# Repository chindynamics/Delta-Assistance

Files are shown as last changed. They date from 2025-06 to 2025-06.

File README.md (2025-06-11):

# Delta Assistance

**Delta Assistance** is an assisted mobility system designed for individuals with paralysis or reduced mobility, controlled through eye-tracking. The project combines computer vision, hardware control, and accessible design to offer a functional, low-cost, and adaptable solution. This repository contains all the code, technical documentation, and resources necessary to replicate or understand the development of the project.

## CONTENT

Below are the sections available to explore the project in more detail:  
- [Introduction](https://github.com/chindynamics/Delta-Assistance/blob/main/docs/en/1.-%20introduction.md): context, motivation, and project objectives.  
- [Installation](https://github.com/chindynamics/Delta-Assistance/blob/main/docs/en/2.-%20installation.md): step-by-step guide to clone the repository, install dependencies, and run the system.  
- [Documentation](https://github.com/chindynamics/Delta-Assistance/blob/main/docs/en/3.-%20documentation.md): full technical explanation of the design, integration, and validation process.

## FEATURES

The Delta Assistance system is designed to be accessible, modular, and adaptable. Its main innovation lies in the use of computer vision to interpret the user's gaze direction and convert it into commands to move a powered wheelchair. The eye-tracking interface was developed in Python based on Jason Orlosky's open-source code, while motion control was implemented on an Arduino Mega microcontroller using C++. This combination enables efficient communication between the user and the machine, even without physical contact.

In addition to the eye-tracking interface, a custom circuit board was designed to control the wheelchair motors, and a physical structure was adapted to integrate with a conventional wheelchair. The system is capable of recognizing five commands: move forward, move backward, turn left, turn right, and stop. Its design takes into account real-world environments, including varying lighting conditions and physical interference.

## COLLABORATION

This project was developed by the Delta Assistance team:

- [@chindynamics](https://github.com/chindynamics) – Lead on computer vision pipeline and human–computer interaction design.
- [@Sarao2341](https://github.com/Sarao2341) – Responsible for 3D modeling and mechanical integration.
- [@reginaruizz](https://github.com/reginaruizz) – PCB schematic and layout. Selected components for the power regulation stages.
- [@Ulin78](https://github.com/Ulin78) – Electronics integration and firmware support. Assisted with PCB bring-up.
- [@haydeevazquez](https://github.com/haydeevazquez) – Sound processing and obstacle detection.
- [@mirelyyc](https://github.com/mirelyyc) – UI and iconography designer. Created the visual assets for the desktop interface.

If you're interested in improving this system, adapting it to new needs, or contributing your expertise in software, hardware, or accessible design, you're welcome to collaborate. You can do so by opening an issue to report problems or suggestions, or by submitting a pull request with specific improvements. This project may also serve as an educational or research base for further developments in biomedical engineering and assistive technologies.

## LICENSE

This project is distributed under the [MIT License](https://github.com/chindynamics/Delta-Assistance/blob/main/LICENSE), meaning you are free to use, modify, and redistribute the code and resources shared here, as long as proper credit is given to the original authors.

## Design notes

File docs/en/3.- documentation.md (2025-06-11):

# DEVELOPMENT DOCUMENTATION

This section outlines step-by-step how the Delta Assistance project was developed—an electric wheelchair controlled by eye-tracking, aimed at improving mobility for individuals with paralysis or severe motor disabilities. Below are the detailed phases of the process, from initial concept to final system integration.

## SYSTEM DESIGN

The architecture was based on three main components:
- An eye-tracking interface that captures the user's gaze position to interpret movement commands within a digital interface designed using Qt Designer.
- An Arduino Mega microcontroller to interpret the signals sent from the Raspberry Pi and transmit commands to the wheelchair motors.
- A motor control system that moves the wheelchair in the desired direction safely.

## SOFTWARE DEVELOPMENT

The software was divided into two layers. The first is a visual interface developed in Python, which uses computer vision to analyze eye position and determine whether the user wants to move forward, backward, left, right, or stop. This interface translates the gaze direction into signals sent to the second layer: the microcontroller.  
The Arduino Mega was programmed in C++ using the Arduino environment. Its function is to receive commands, generate the appropriate motor control signals (using PWM), and ensure precise and safe control. Debugging messages were also included to facilitate testing.

## HARDWARE DEVELOPMENT

On the physical side, a standard wheelchair was modified by adding electronically controllable motors. A custom PCB was designed to mount the Arduino Mega and other components, such as voltage regulators and connection ports.  
An autonomous power system with rechargeable batteries was integrated, along with a fixed mount for the eye-tracking camera, positioned in front of the user's face. The entire system was built with a focus on ease of maintenance and durability for continuous use.

## INTEGRATION AND CALIBRATION

Once both the software and hardware stages were completed, all modules were integrated. An initial calibration process was designed for each user, allowing adjustment of eye sensitivity values.  
Various lighting conditions and distances were tested to ensure the system functions reliably under real-world scenarios.

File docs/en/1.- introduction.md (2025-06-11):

# INTRODUCTION

Neuromuscular conditions such as amyotrophic lateral sclerosis (ALS) or spinal cord injuries lead to progressive mobility loss, forcing patients into critical dependency for daily activities. In response to this challenge, our project presents an electric wheelchair controlled by eye tracking, a solution that empowers users to regain autonomy through technology. Unlike commercial systems that require physical components (such as joysticks or switches), our prototype interprets the user's intention to move directly from their gaze, removing barriers for those who have lost muscular control.

The system combines computer vision algorithms for iris tracking with a semi-autonomous navigation module. Using a low-cost camera and real-time image processing techniques, the software translates eye coordinates into directional commands (forward, backward, turns) that are sent to an Arduino Mega controller. At the same time, ultrasonic sensors and an integrated accelerometer detect obstacles within a 1.5-meter radius, activating automatic brakes when collision risk exceeds predefined thresholds. This safety layer is essential for indoor environments with limited space.

Statistics emphasize the urgency of such solutions, ALS has a global incidence of 1.9 cases per 100,000 people, with a projected 69% increase by 2040 due to population aging. Yet, access to assistive technologies remains limited.

This project not only demonstrates the technical feasibility of accessible systems, but also opens the door to future improvements.

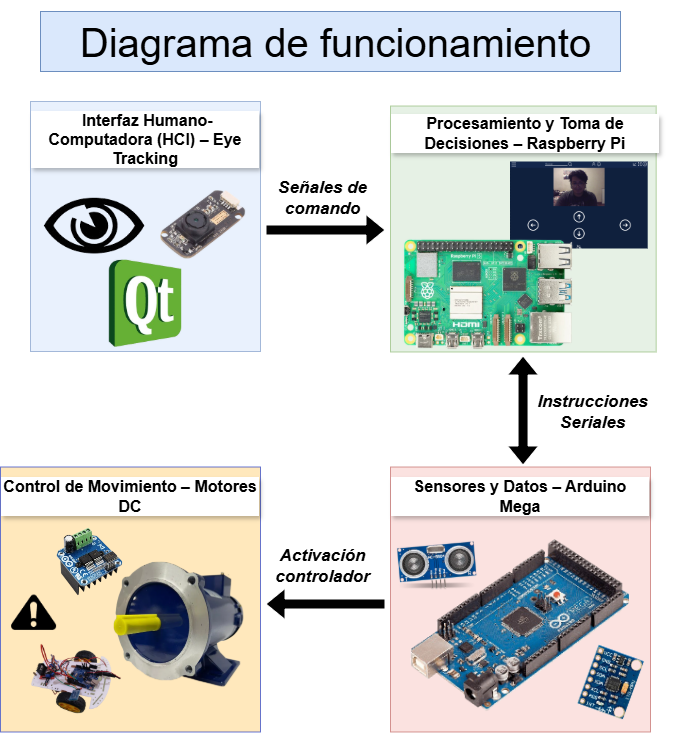
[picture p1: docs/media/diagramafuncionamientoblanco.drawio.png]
System Architecture


*Figure 1: System data flow. The camera captures eye movement, the algorithm translates it into coordinates, and Arduino sends signals to the motors, while ultrasonic sensors monitor the surroundings.*

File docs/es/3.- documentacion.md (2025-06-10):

# DOCUMENTACIÓN DE DESARROLLO

Este apartado describe paso a paso cómo se llevó a cabo el desarrollo del proyecto Delta Assistance, una silla de ruedas eléctrica controlada mediante seguimiento ocular, orientada a mejorar la movilidad de personas con parálisis o discapacidades motoras severas. A continuación se detallan las fases del proceso, desde la concepción inicial hasta la integración final de los sistemas.

## DISEÑO DEL SISTEMA

Se planteó una arquitectura basada en tres elementos principales:
- Una interfaz de seguimiento ocular. Captura la posición de la mirada del usuario para interpretar comandos de movimiento en una interfaz digital diseñada en Qt Designer.
- Un microcontrolador Arduino Mega para interpretar las señales mandadas desde el Raspberry Pi y enviar comandos a los motores de la silla.
- Un sistema de control de motores que mueve la silla de ruedas en la dirección deseada de forma segura.

## DESARROLLO DE SOFTWARE

El sistema de software se dividió en dos niveles. El primero es una interfaz visual desarrollada en Python, utilizando visión por computadora para analizar la posición de los ojos y determinar si el usuario desea moverse hacia adelante, atrás, a la izquierda, a la derecha o detenerse. Esta interfaz traduce la dirección de la mirada en señales que son enviadas al segundo nivel: el microcontrolador. El Arduino Mega fue programado en C++ mediante el entorno de Arduino, y su función es recibir los comandos, generar las señales adecuadas para los motores (usando PWM) y garantizar un control preciso y seguro. También se incluyeron mensajes de depuración para facilitar las pruebas.

## DESARROLLO DE HARDWARE

En el aspecto físico, se adaptó una silla de ruedas convencional agregando motores controlables electrónicamente. Se diseñó una PCB personalizada para montar el Arduino Mega y otros componentes como reguladores de voltaje y puertos de conexión. Además, se integró un sistema de energía autónoma con baterías recargables, y un soporte fijo para la cámara encargada del seguimiento ocular, ubicada frente al rostro del usuario. Todo el sistema fue construido considerando la facilidad de mantenimiento y la robustez frente al uso continuo.

## INTEGRACIÓN Y CALIBRACIÓN

Una vez finalizadas las etapas de software y hardware, se llevó a cabo la integración de todos los módulos. Se diseñó un proceso de calibración inicial para cada usuario, donde se ajustan los valores de sensibilidad ocular. También se probaron diferentes condiciones de iluminación y distancias para asegurar que el sistema funcionara correctamente en situaciones reales.

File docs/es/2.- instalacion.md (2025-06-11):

# INSTALACIÓN

Este apartado proporciona una guía paso a paso para instalar y configurar correctamente el sistema de control de la silla de ruedas eléctrica con seguimiento ocular. El objetivo es asegurar que cualquier usuario o desarrollador pueda poner en marcha el entorno de software y hardware sin complicaciones.

## REQUISITOS PREVIOS

Antes de comenzar con la instalación, asegurate de tener lo siguiente instalado:
- Una computadora con un sistema operativo Linux o Windos (no probado en macOS) o un Raspberry Pi.
- Un microcontrolador Arduino Mega, correctamente flasheado con el código proporcionado para Arduino.
- Una cámara infrarroja, para este proyecto se usó una cámara GC0308.
- Librerías de Python requeridas para el procesamiento de imágenes.

## CLONA EL REPOSITORIO

Clona este repositorio en tu máquina local usando el comando:

```bash
git clone https://github.com/chindynamics/Delta-Assistance.git
cd Delta-Assistance
```

## INSTALA LAS DEPENDENCIAS

Una vez clonado el repositorio, instala las dependencias necesarias. Se recomienda crear un entorno virtual de Python 3.11:

```bash
python -m venv venv
source venv/bin/activate
pip install -r requirements.txt
```

## PRIMER INICIO

Ejecuta el script principal **HCI.py** del sistema de seguimiento ocular para verificar la calibración y comunicación con el microcontrolador.

Al ejecutar este código, el sistema calibrará el seguimiento ocular. Observe los puntos en pantalla y presione la barra espaciadora para capturar los puntos de calibración, repita este proceso para cada punto para completar el proceso. Una vez calibrado, puede activar el control de movimiento desde la interfaz proporcionada usando el seguimiento ocular.

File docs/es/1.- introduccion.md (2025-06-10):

# INTRODUCCIÓN

Los padecimientos neuromusculares como la esclerosis lateral amiotrófica (ELA) o las lesiones medulares generan una pérdida progresiva de la movilidad, relegando a los pacientes a una dependencia crítica de terceros para actividades cotidianas. Frente a este desafío, nuestro proyecto desarrolla una silla de ruedas eléctrica controlada mediante seguimiento ocular, una solución que empodera a los usuarios reconquistando su autonomía a través de la tecnología. A diferencia de sistemas comerciales que requieren componentes físicos (como joysticks o pulsadores), nuestro prototipo interpreta la intención de movimiento directamente desde la mirada, eliminando barreras para quienes han perdido el control muscular.

El sistema combina algoritmos de visión por computadora para el rastreo del iris con un módulo de navegación autónoma. Utilizando una cámara de bajo costo y técnicas de procesamiento de imágenes en tiempo real, el software traduce coordenadas oculares en comandos direccionales (avance, retroceso, giros) que son enviados a un controlador Arduino Mega. Paralelamente, sensores ultrasónicos y un acelerómetro integrado detectan obstáculos en un radio de 1.5 metros, activando frenos automáticos cuando el riesgo de colisión supera umbrales predefinidos. Esta capa de seguridad es clave para entornos domésticos con espacios reducidos.

Las estadísticas subrayan la urgencia de estas soluciones, la incidencia global de ELA alcanza 1.9 casos por cada 100,000 personas, con un crecimiento proyectado del 69% para 2040 debido al envejecimiento poblacional. Sin embargo, el acceso a tecnologías asistivas sigue siendo limitado. 

Este proyecto no solo demuestra la viabilidad técnica de sistemas accesibles, sino que también abre puertas a futuras mejoras.

Arquitectura de Sistema

*Figura 1: Flujo de datos del sistema. La cámara captura el movimiento ocular, el algoritmo lo traduce en coordenadas, y Arduino envía señales a los motores, mientras los sensores ultrasónicos monitorizan el entorno.*

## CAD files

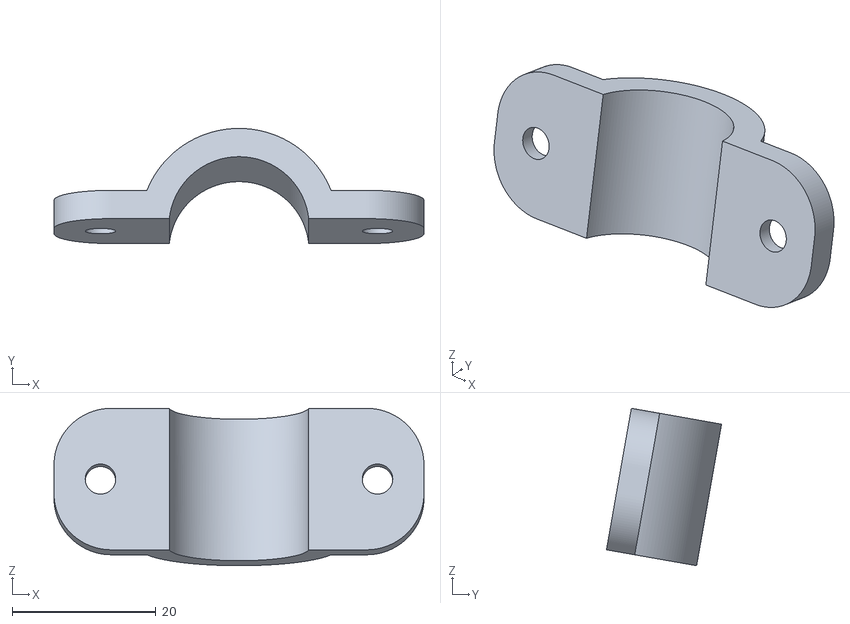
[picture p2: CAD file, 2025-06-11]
src/3D-modeling/CLAMP_ULTRASONICO.stl
51.5 x 16.0 x 21.9

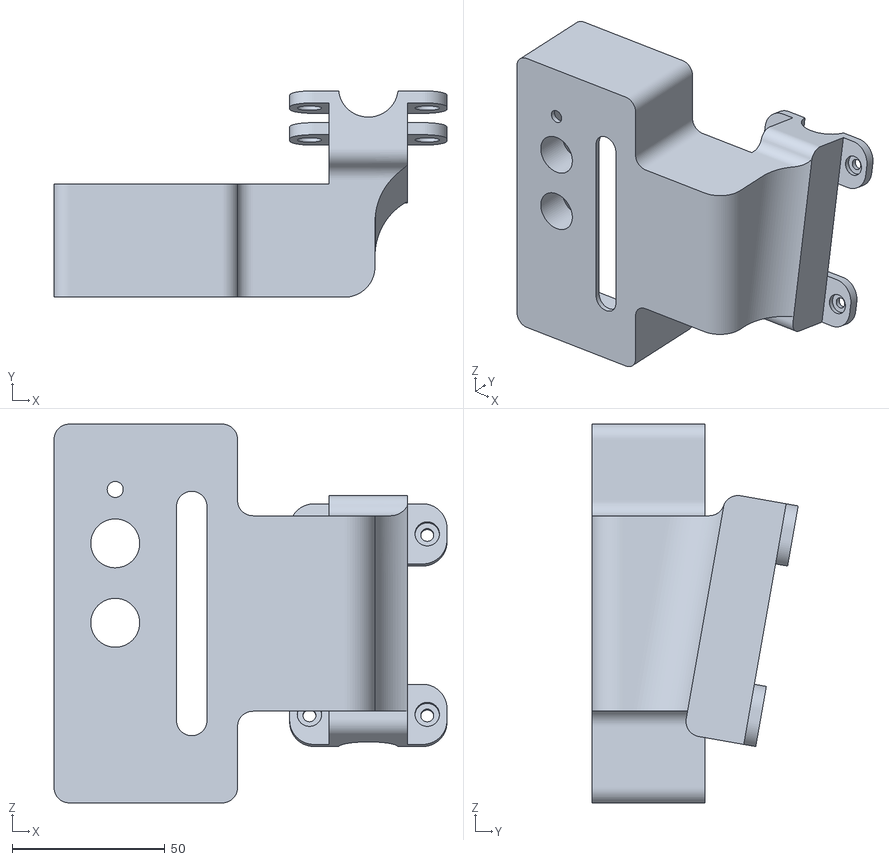
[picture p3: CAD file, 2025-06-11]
src/3D-modeling/DERECHACASE.stl
128.7 x 67.6 x 124.0

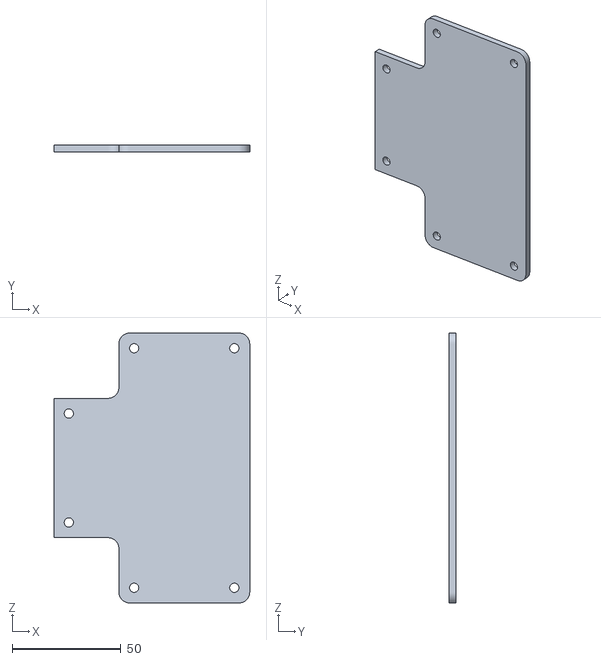
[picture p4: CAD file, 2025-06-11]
src/3D-modeling/IZQUIERDATAPA.stl
89.8 x 3.00 x 124.0

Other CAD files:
src/3D-modeling/IZQUIERDACASE.stl
src/3D-modeling/DERECHATAPA.stl
src/3D-modeling/EJE_MOTOR_REV2 v2.f3d
src/3D-modeling/ENSAMBLE_MONITOR v5.f3d
src/3D-modeling/EYETRACKER_SUPPORT v5.f3d
src/3D-modeling/MecanismoFreno v8 v2.f3d
src/3D-modeling/SENSOR TRASERO_DELTA_ULTRASÓNICO v5.f3z
src/3D-modeling/SOPORTE BOCINAS_DELTA v2.f3d
src/3D-modeling/sensores delantero v4.f3z

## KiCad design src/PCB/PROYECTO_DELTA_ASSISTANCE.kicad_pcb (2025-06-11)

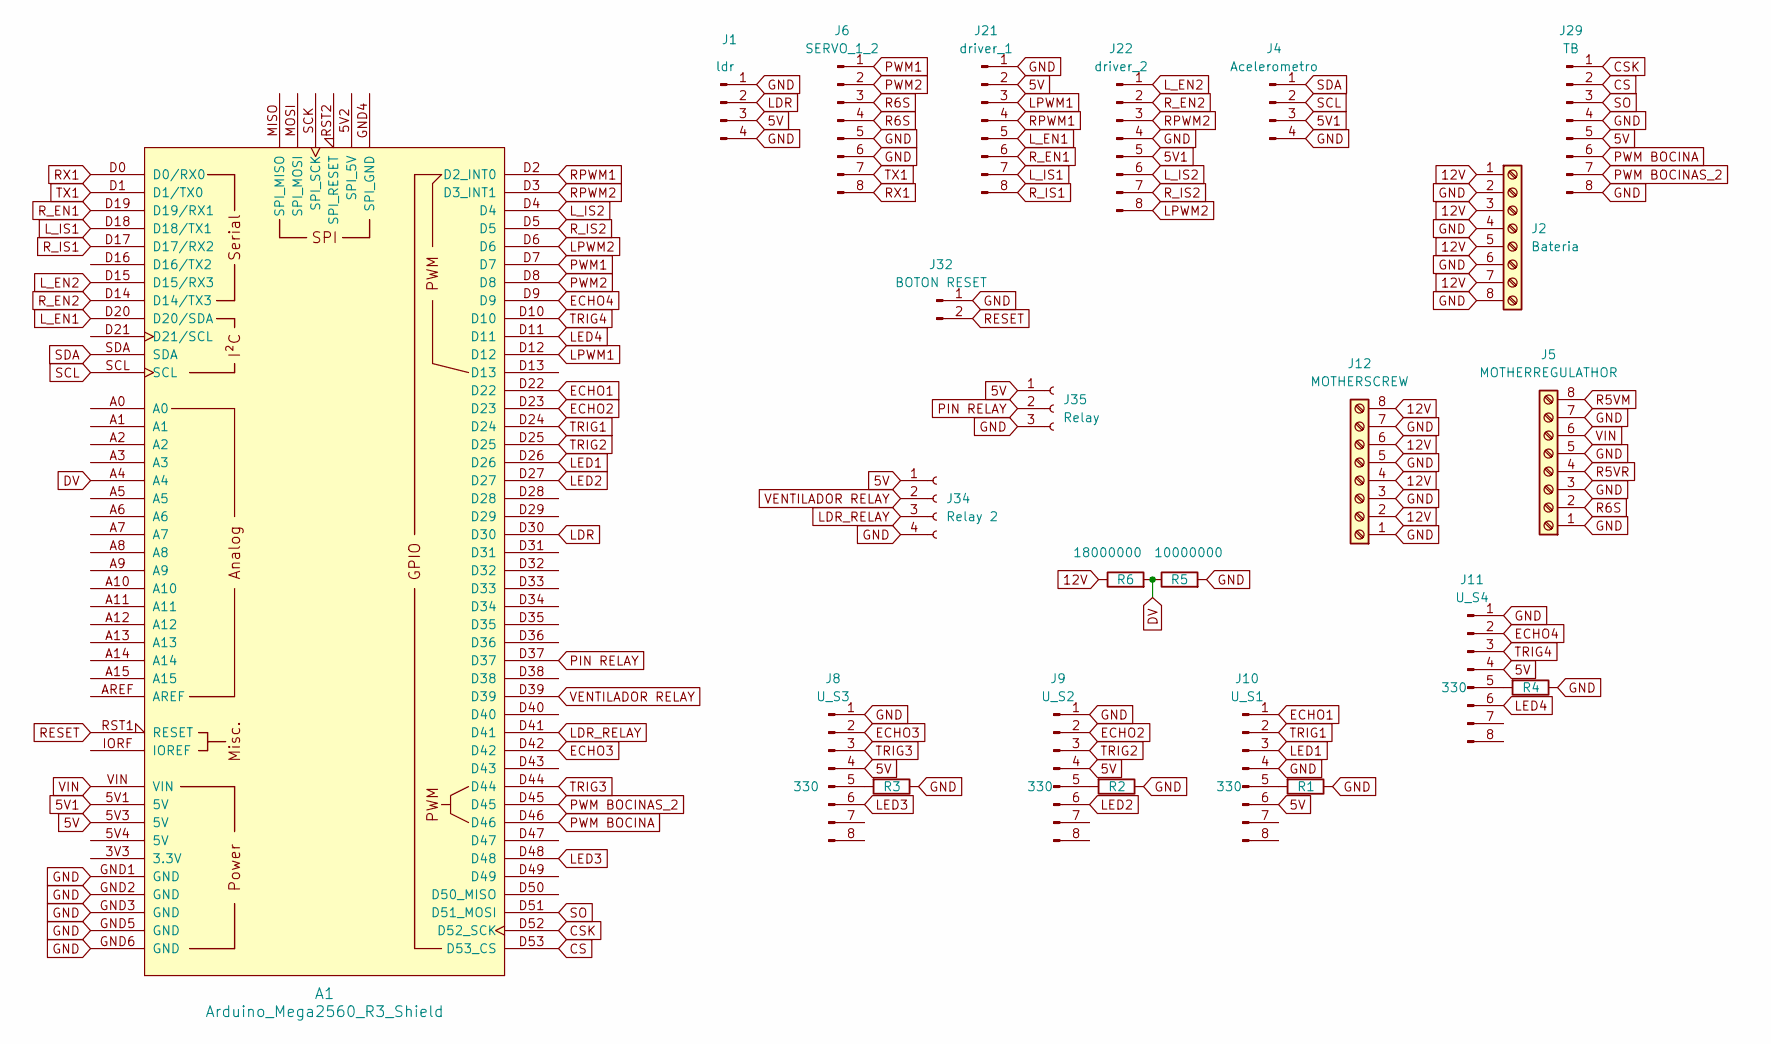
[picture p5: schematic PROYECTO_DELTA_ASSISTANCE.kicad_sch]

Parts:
A1: Arduino_Mega2560_R3_Shield
J1: ldr; JST_XH_B4B-XH-A_1x04_P2.50mm_Vertical
J2: Bateria; TerminalBlock_Phoenix_MKDS-1,5-8-5.08_1x08_P5.08mm_Horizont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
J4: Acelerometro; JST_XH_B4B-XH-A_1x04_P2.50mm_Vertical
J5: MOTHERREGULATHOR; TerminalBlock_Phoenix_MKDS-1,5-8-5.08_1x08_P5.08mm_Horizont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
J6: SERVO_1_2; JST_XH_B8B-XH-A_1x08_P2.50mm_Vertical
J8: U_S3; JST_XH_B8B-XH-A_1x08_P2.50mm_Vertical
J9: U_S2; JST_XH_B8B-XH-A_1x08_P2.50mm_Vertical
J10: U_S1; JST_XH_B8B-XH-A_1x08_P2.50mm_Vertical
J11: U_S4; JST_XH_B8B-XH-A_1x08_P2.50mm_Vertical
J12: MOTHERSCREW; TerminalBlock_Phoenix_MKDS-1,5-8-5.08_1x08_P5.08mm_Horizont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
J21: driver_1; JST_XH_B8B-XH-A_1x08_P2.50mm_Vertical
J22: driver_2; JST_XH_B8B-XH-A_1x08_P2.50mm_Vertical
J29: TB; JST_XH_B8B-XH-A_1x08_P2.50mm_Vertical
J32: BOTON RESET; JST_XH_B2B-XH-A_1x02_P2.50mm_Vertical
J34: Relay 2; PinHeader_1x04_P2.54mm_Vertical
J35: Relay; PinHeader_1x03_P2.54mm_Vertical
R1, R2, R3, R4: 330; R_Axial_DIN0207_L6.3mm_D2.5mm_P10.16mm_Horizontal
R5: 10000000; R_Axial_DIN0207_L6.3mm_D2.5mm_P10.16mm_Horizontal
R6: 18000000; R_Axial_DIN0207_L6.3mm_D2.5mm_P10.16mm_Horizontal

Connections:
5V: A1.5V3 (5V), J1.3, J8.4, J9.4, J10.6, J11.4, J21.2, J29.5, J34.1, J35.1
5V1: A1.5V1 (5V), J4.3, J22.5
12V: J2.1, J2.3, J2.5, J2.7, J12.2, J12.4, J12.6, J12.8, R6.1
CS: A1.D53 (D53_CS), J29.2
CSK: A1.D52 (D52_SCK), J29.1
DV: A1.A4, R5.1, R6.2
ECHO1: A1.D22, J10.1
ECHO2: A1.D23, J9.2
ECHO3: A1.D42, J8.2
ECHO4: A1.D9, J11.2
GND: A1.GND1 (GND), A1.GND2 (GND), A1.GND3 (GND), A1.GND5 (GND), A1.GND6 (GND), J1.1, J1.4, J2.2, J2.4, J2.6, J2.8, J4.4, J5.1, J5.3, J5.5, J5.7, J6.5, J6.6, J8.1, J9.1, J10.4, J11.1, J12.1, J12.3, J12.5, J12.7, J21.1, J22.4, J29.4, J29.8, J32.1, J34.4, J35.3, R1.1, R2.1, R3.1, R4.1, R5.2
LDR: A1.D30, J1.2
LDR_RELAY: A1.D41, J34.3
LED1: A1.D26, J10.3
LED2: A1.D27, J9.6
LED3: A1.D48, J8.6
LED4: A1.D11, J11.6
LPWM1: A1.D12, J21.3
LPWM2: A1.D6, J22.8
L_EN1: A1.D20 (D20/SDA), J21.5
L_EN2: A1.D15 (D15/RX3), J22.1
L_IS1: A1.D18 (D18/TX1), J21.7
L_IS2: A1.D4, J22.6
unnamed: J8.5, R3.2
unnamed: J9.5, R2.2
unnamed: J10.5, R1.2
unnamed: J11.5, R4.2
PIN RELAY: A1.D37, J35.2
PWM1: A1.D7, J6.1
PWM2: A1.D8, J6.2
PWM BOCINA: A1.D46, J29.6
PWM BOCINAS_2: A1.D45, J29.7
R5VM: J5.8
R5VR: J5.4
R6S: J5.2, J6.3, J6.4
RESET: A1.RST1 (RESET), J32.2
RPWM1: A1.D2 (D2_INT0), J21.4
RPWM2: A1.D3 (D3_INT1), J22.3
RX1: A1.D0 (D0/RX0), J6.8
R_EN1: A1.D19 (D19/RX1), J21.6
R_EN2: A1.D14 (D14/TX3), J22.2
R_IS1: A1.D17 (D17/RX2), J21.8
R_IS2: A1.D5, J22.7
SCL: A1.SCL, J4.2
SDA: A1.SDA, J4.1
SO: A1.D51 (D51_MOSI), J29.3
TRIG1: A1.D24, J10.2
TRIG2: A1.D25, J9.3
TRIG3: A1.D44, J8.3
TRIG4: A1.D10, J11.3
TX1: A1.D1 (D1/TX0), J6.7
VENTILADOR RELAY: A1.D39, J34.2
VIN: A1.VIN, J5.6

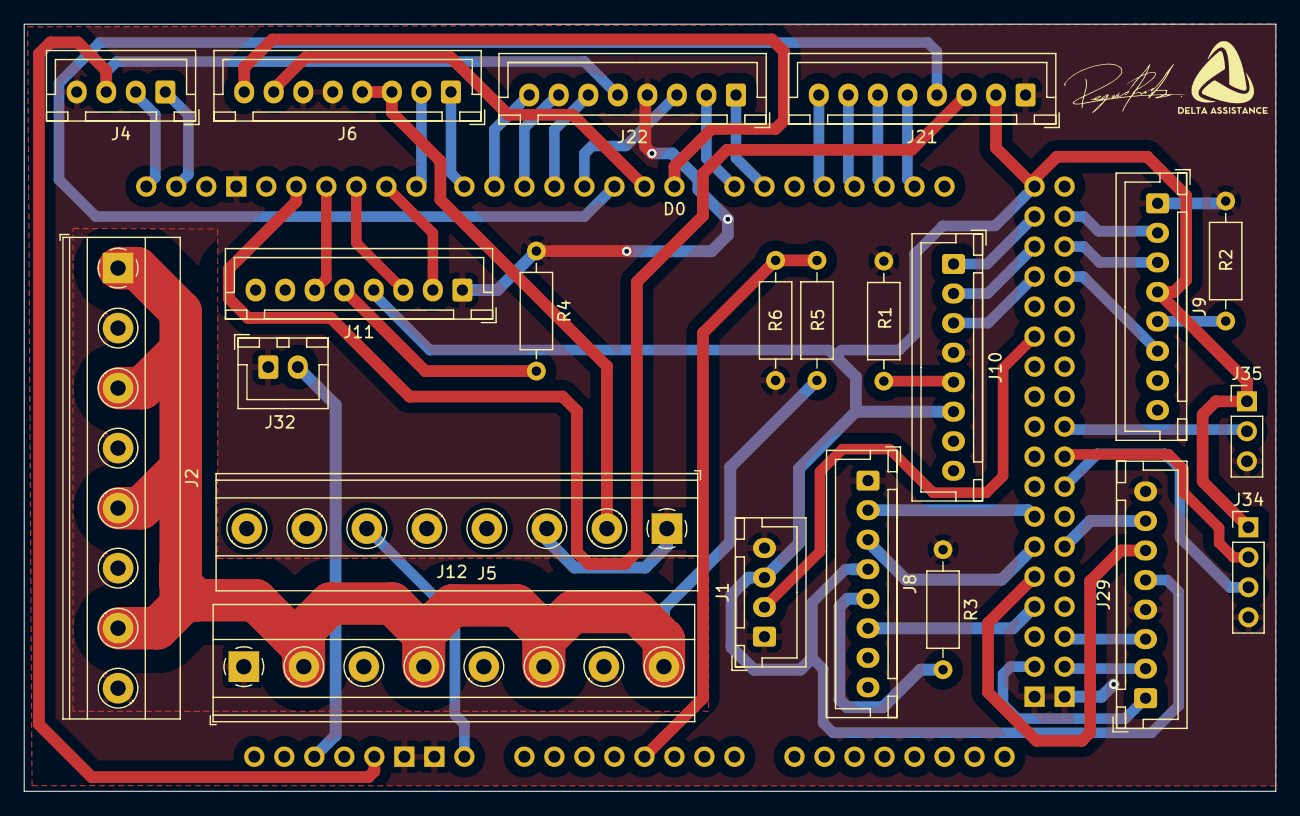
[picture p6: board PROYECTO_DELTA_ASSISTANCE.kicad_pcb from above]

Board: 2 copper layers, 105.9 x 64.9 mm, 23 parts (0 on the bottom side), 51 nets.

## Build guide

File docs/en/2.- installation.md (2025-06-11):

# INSTALLATION

This section provides a step-by-step guide to correctly install and configure the control system for the eye-tracking electric wheelchair. The goal is to ensure that any user or developer can set up the software and hardware environment without complications.

## PREREQUISITES

Before beginning the installation, make sure you have the following:
- A computer running Linux or Windows (macOS not tested), or a Raspberry Pi.
- An Arduino Mega microcontroller, properly flashed with the provided Arduino code.
- An infrared camera; this project used a GC0308 camera.
- Required Python libraries for image processing.

## CLONE THE REPOSITORY

Clone this repository to your local machine using the command:

```bash
git clone https://github.com/chindynamics/Delta-Assistance.git
cd Delta-Assistance
```

## INSTALL DEPENDENCIES

Once the repository is cloned, install the necessary dependencies. It is recommended to create a Python 3.11 virtual environment:

```bash
python -m venv venv
source venv/bin/activate
pip install -r requirements.txt
```

## FIRST RUN

Run the main script HCI.py from the eye-tracking system to verify calibration and communication with the microcontroller.

When you run this code, the system will begin the eye-tracking calibration. Observe the calibration points on the screen and press the spacebar to capture each point. Repeat the process until all calibration points are completed. Once calibrated, you can activate movement control from the provided interface using eye-tracking.

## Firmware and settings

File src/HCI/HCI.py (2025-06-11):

#!/usr/bin/env python3

#---------------------------------------------------IMPORTAR LIBRERÍAS-------------------------------------------------------

import sys
import os
import time
import serial # Importar
from PySide6 import *
from PySide6.QtCore import QPropertyAnimation, QThread, Signal, Slot, QTimer, QEvent  # Importa directamente la clase
import cv2
import numpy as np
import pyautogui

#---------------------------------------------------IMPORTAR EYETRACKING----------------------------------------------------------

from deltatrackersmall import calibrate, train_mapping, process_frame, camera_w, camera_h, SCREEN_W, SCREEN_H, smooth_center, process_video

#---------------------------------------------------IMPORTAR ARCHIVO GUI-------------------------------------------------------


from ui_delta import *


#---------------------------------------------------CREAR CLASE PARA EYETRACKING---------------------------------------------------------


class EyeTrackerThread(QThread):
    def __init__(self, a_coeffs, b_coeffs, camera_index=1, alpha_percent=80, parent=None):
        super().__init__(parent)
        self.a = a_coeffs
        self.b = b_coeffs
        self.camera_index = camera_index
        self.alpha = alpha_percent
        self.stop_flag = False

    def run(self):
        try:
            #VERIFICAR SI LA CAMARA ESTA FUNCIONANDO
            cap = cv2.VideoCapture(self.camera_index)
            if not cap.isOpened():
                print(f"[ERROR] No se pudo abrir la cámara {self.camera_index}")
                return
            cap.release()

            print("[EyeTrackerThread] Llamando a process_video...")
            process_video(
                input_method=2,
                camera_index=self.camera_index,
                alpha_percent=self.alpha,
                a_coeffs=self.a,
                b_coeffs=self.b,
                stop_flag=lambda: self.stop_flag,
                show_window=False
            )
        except Exception as e:
            # Capturamos cualquier error e imprimimos para que no cierre todo
            print(f"[EyeTrackerThread] Excepción en process_video: {e}")
            import traceback
            traceback.print_exc()

    def stop(self):
        self.stop_flag = True
        # cv2.destroyAllWindows()  # cierra cualquiera de las ventanas OpenCV
        # self.quit()
        self.wait()

#---------------------------------------------------CREAR CLASE PARA LA CÁMARA-------------------------------------------------------

class CameraThread(QThread):

    frame_ready = Signal(QtGui.QImage) #Señal para enviar el frame procesado

    def __init__(self, camera_index=0, parent=None):
        super().__init__()
        self.camera_index = camera_index
        self.running = True

    def run(self):
        cap = cv2.VideoCapture(self.camera_index)
        while self.running:
            ret, frame = cap.read()
            if ret:
                #Convertir de BGR a RGB y a un QImage
                rgb_image = cv2.cvtColor(frame, cv2.COLOR_BGR2RGB)
                h, w, ch = rgb_image.shape
                bytes_per_line = ch * w
                qt_image = QtGui.QImage(rgb_image.data, w, h, bytes_per_line, QtGui.QImage.Format_RGB888)
                self.frame_ready.emit(qt_image)
            time.sleep(0.01) #Liberar CPU
        cap.release()

    def stop(self):
        self.running = False
        self.wait()

#---------------------------------------------------CREAR CLASE DE VENTANA PRINCIPAL-------------------------------------------------------

class MainWindow(QtWidgets.QMainWindow):
    def __init__(self, a_coeffs, b_coeffs):
        super().__init__()
        self.ui = Ui_MainWindow()
        self.ui.setupUi(self)
        self.setWindowFlags(QtCore.Qt.FramelessWindowHint) #Quita la barra de título de ventana
        #self.setAttribute(QtCore.Qt.WA_TranslucentBackground) #Pone el fondo principal transparante
        self.shadow = QGraphicsDropShadowEffect(self) #Empieza a crear un efecto de sombra
        self.shadow.setBlurRadius(50)
        self.shadow.setXOffset(0)
        self.shadow.setYOffset(0)
        self.shadow.setColor(QColor(0, 92, 157, 550))
        self.ui.centralwidget.setGraphicsEffect(self.shadow) #Aplica la sombra al widget central

        #Los íconos y título no se verán porque quitamos la barra de título
        self.setWindowIcon(QtGui.QIcon(u":/iconos/iconsselect/Delta.svg")) #Poner icono a la ventana
        self.setWindowTitle("Delta UI")
        QSizeGrip(self.ui.size_grip) #Crear lugar para agarrar ventana y modificar tamaño
        self.ui.minimize_window_button.clicked.connect(lambda: self.showMinimized()) #Minimizar ventana
        self.ui.close_window_button.clicked.connect(lambda: self.close()) #Cerrar ventana con botón de cerrado
        self.ui.exit_button.clicked.connect(lambda: self.close()) #Cerrar ventana con botón de salir
        #Configuración serial Python - Arduino
        self.serial_port = "/dev/ttyACM0" #Modificar a lo necesario
        self.baud_rate = 9600 #Modificar a lo necesario

        # En el __init__ de MainWindow:
        try:
            self.arduino = serial.Serial(port = self.serial_port, baudrate = self.baud_rate, timeout = 0.5, write_timeout =0.5)
            time.sleep(2) # Espera a que Arduino se inicialice.
            print("Conexión serial establecida correctamente")
        except Exception as e:
            print(f"Error de conexión: {str(e)}")
            QtWidgets.QMessageBox.critical(self, "Error de conexión", f"No se pudo conectar al Arduino: {self.serial_port}:\n{str(e)}")
            self.arduino = None  # Añadir este atributo para verificar conexión

        self.debounce_interval = 0.5 #ms

        self.buttons_commands = {
            'up': {
                'last_time': 0, 
                'msg': 'Arriba presionado',
                'command': ['U']
            },
            'down': {
                'last_time': 0,
                'msg': 'Abajo presionado',
                'command': ['D']
            },
            'right': {
                'last_time': 0,
                'msg': 'Derecha presionado',
                'command': ['R']
            },
            'left': {
                'last_time': 0,
                'msg': 'Izquierda presionado',
                'command': ['L']
            },
            'exit1': {
                'last_time': 0,
                'msg': 'Salida1 presionado',
                'command': ['exit1']
            },
            'exit2': {
                'last_time': 0,
                'msg': 'Salida2 presionado',
                'command': ['exit2']
            },
            'stop': {
                'last_time': 0,
                'msg': 'Parar presionado',
                'command': ['B']
            },
            'assistance': {
                'last_time': 0,
                'msg': 'Asistencia presionado',
                'command': ['Assistance']
            },
            'company': {
                'last_time': 0,
                'msg': 'Compania presionado',
                'command': ['Company']
            },
            'entertainment': {
                'last_time': 0,
                'msg': 'Entretenimiento presionado',
                'command': ['Entertainment']
            },
            'food': {
                'last_time': 0,
                'msg': 'Comida presionado',
                'command': ['Food']
            },
            'toilet': {
                'last_time': 0,
                'msg': 'Banio presionado',
                'command': ['Toilet']
            },
            'water': {
                'last_time': 0,
                'msg': 'Agua presionado',
                'command': ['Water']
            },
            'slide': {
                'last_time': 0,
                'msg': 'Slide presionado',
                'command': ['Slide']
            },
            'minimize': {
                'last_time': 0,
                'msg': 'Minimizar presionado',
                'command': ['min']
            }
        }


        self.ui.up_button.clicked.connect(lambda: self.handle_button('up'))  #Mostrar en el monitor serial que el botón fue presionado
        self.ui.down_button.clicked.connect(lambda:self.handle_button('down'))  #Mostrar en el monitor serial que el botón fue presionado
        self.ui.left_button.clicked.connect(lambda:self.handle_button('left'))  #Mostrar en el monitor serial que el botón fue presionado
        self.ui.right_button.clicked.connect(lambda:self.handle_button('right'))  #Mostrar en el monitor serial que el botón fue presionado
        self.ui.exit_button.clicked.connect(lambda: self.handle_button('exit1'))
        self.ui.close_window_button.clicked.connect(lambda: self.handle_button('exit2'))
        self.ui.stop_button.clicked.connect(lambda:self.handle_button('stop')) #Mostrar en el monitor serial que el botón fue presionado
        self.ui.ask_assistance_btn.clicked.connect(lambda:self.handle_button('assistance'))
        self.ui.ask_company_btn.clicked.connect(lambda:self.handle_button('company'))
        self.ui.ask_entertenaiment_btn.clicked.connect(lambda:self.handle_button('entertainment'))
        self.ui.ask_food_btn.clicked.connect(lambda:self.handle_button('food'))
        self.ui.ask_toilet_btn.clicked.connect(lambda:self.handle_button('toilet'))
        self.ui.ask_water_btn.clicked.connect(lambda:self.handle_button('water'))
        self.ui.open_close_side_bar_btn.clicked.connect(lambda:self.handle_button('slide')) #Prender y quitar menú de izquierda

        self.ui.minimize_window_button.clicked.connect(lambda: self.handle_button('minimize'))
        self.ui.restore_window_button.clicked.connect(lambda: self.handle_button('max'))
        

        #Añadir función de restaurar / maximizar pantalla
        self.ui.restore_window_button.clicked.connect(lambda: self.restore_or_maximize_window())

        self.velocidades = ['lenta', 'normal', 'rápida']
        self.idx = 0

        self.ui.speed_btn.clicked.connect(self.cambiar_velocidad)
        


        self.hover_threshold = 1000 #Umbral para hacer click en el boton si se hace hover en ms

        #Creación de timers para cada boton
        self.hover_timers = {}
        for name, btn in {
            'up': self.ui.up_button,
            'down': self.ui.down_button,
            'left': self.ui.left_button,
            'right': self.ui.right_button,
            'exit1': self.ui.exit_button,
            'exit2': self.ui.close_window_button,
            'stop': self.ui.stop_button,
            'slide': self.ui.open_close_side_bar_btn,
            'assistance': self.ui.ask_assistance_btn,
            'company': self.ui.ask_company_btn,
            'entertainment': self.ui.ask_entertenaiment_btn,
            'food': self.ui.ask_food_btn,
            'toilet': self.ui.ask_toilet_btn,
            'water': self.ui.ask_water_btn,
            'slide': self.ui.open_close_side_bar_btn,
            'min': self.ui.minimize_window_button,
            'max': self.ui.restore_window_button
        }.items():
            timer = QTimer(self, singleShot=True)
            timer.timeout.connect(lambda n=name: self.handle_button(n))
            self.hover_timers[btn] = timer
            #Instalar filtro de eventos
            btn.installEventFilter(self)


        #Función para mover la ventana con drag del mouse en la barra de título.
        def moveWindow(e):
            #Detecta si la ventana está en tamaño normal
            if self.isMaximized() == False: #No maximizado
                #Mover ventana solo cuando está en tamaño normal
                #Si el botón del mouse izquierdo se presiona...
                if e.buttons() == Qt.LeftButton:  
                    #Mover ventana
                    self.move(self.pos() + e.globalPos() - self.clickPosition)
                    self.clickPosition = e.globalPos()
                    e.accept()

        #Añadir evento de click de mouse y movimiento en el header para mover la ventana
        self.ui.header_frame.mouseMoveEvent = moveWindow

        

        #Configuración de cámara
        self.camera_thread = CameraThread(camera_index=0)
        self.camera_thread.frame_ready.connect(self.update_camera_view)
        self.camera_thread.start()
        
        #Asegurarse que la cámara se detenga al cerrar
        self.destroyed.connect(lambda: self.camera_thread.stop())
        
        # #Eyetracking en el fondo
        self.eye_thread = EyeTrackerThread(a_coeffs, b_coeffs, camera_index=2, alpha_percent=20)
        self.eye_thread.start()


        self.show()

    def closeEvent(self, event):
        # Parar el eyetracker
        if hasattr(self, 'eye_thread'):
            self.eye_thread.stop()
            print('Eyetracking closed')
        # Parar la cámara de la UI
        if hasattr(self, 'camera_thread') and self.camera_thread is not None:
            self.camera_thread.stop()
            print('UI Camera closed')
        # Cerrar ventanas OpenCV
        cv2.destroyAllWindows()
        # Cerrar serial
        if getattr(self, 'arduino', None):
            self.arduino.close()
            print('Arduino closed')
        super().closeEvent(event)

    def cambiar_velocidad(self):
        #Incrementar el índice
        self.idx = (self.idx + 1) % len(self.velocidades)
        #Actualizar el texto del botón
        self.ui.speed_btn.setText(f"Velocidad: {self.velocidades[self.idx]}")

    def eventFilter(self, watched, event):
        #Solo nos interesan los botones a los que instalamos filtro
        if watched in self.hover_timers:
            timer = self.hover_timers[watched]
            if event.type() == QEvent.Enter:
                #Iniciar el conteo regresivo
                timer.start(self.hover_threshold)
            elif event.type() == QEvent.Leave:
                #Cancela si se sale antes del umbral
                timer.stop()
        #Dejar que Qt procese el resto normalmente
        return super().eventFilter(watched, event)

    @Slot(QtGui.QImage)
    def update_camera_view(self, image):
        pixmap = QtGui.QPixmap.fromImage(image)
        #Verificar nombre de label, en QtDesigner se llama camera_feed_label
        self.ui.camera_feed_label.setPixmap(pixmap.scaled(
            self.ui.camera_feed_label.size(),
            QtCore.Qt.KeepAspectRatio,
            QtCore.Qt.SmoothTransformation
        ))

    def handle_button(self, btn_name):
        if self.arduino is None:  # Verificar si hay conexión
            return
    
        current_time = time.monotonic()
        # btn_data debe ser de self.buttons_commands
        if btn_name == 'slide':
            self.slideLeftMenu()
        if btn_name == 'exit1' or btn_name == 'exit2':
            self.close()
        if btn_name == 'min':
            self.showMinimized()
        if btn_name == 'max':
            self.restore_or_maximize_window()
        if btn_name in self.buttons_commands:
            btn_data = self.buttons_commands[btn_name]
            
            if current_time - btn_data['last_time'] >= self.debounce_interval:
                print(btn_data['msg'])
                # Enviar solo el carácter sin comas ni separadores
                comando = btn_data['command'][0] + '\n'
                self.arduino.write(comando.encode('ascii'))
                self.arduino.flush() #Asegurar envio inmediato
                btn_data['last_time'] = current_time
                print(f"Enviado: {comando.strip()}")

    #Función para prender y quitar menú izquierda
    def slideLeftMenu(self):
        self.setAttribute(QtCore.Qt.WA_TranslucentBackground, False)  # Desactiva translucidez
        #Conseguir el ancho del menú izquierdo actual
        width = self.ui.slide_menu_container.width()

        #Si está minimizado
        if width == 0:
            #Expandir el menú
            newWidth = 300
            self.ui.open_close_side_bar_btn.setIcon(QtGui.QIcon(u":/iconos/iconsselect/IconoirMenu.svg"))
        #Si está maximizado
        else:
            #Restaurar menú
            newWidth = 0
            self.ui.open_close_side_bar_btn.setIcon(QtGui.QIcon(u":/iconos/iconsselect/IconoirMenu.svg"))

        self.animation = QPropertyAnimation(self.ui.slide_menu_container, b"maximumWidth") #Animar
        #Minimo ancho   
        self.animation.setDuration(400) #
        self.animation.setStartValue(width) #El valor inicial es el ancho del menú actual
        self.animation.setEndValue(newWidth) #El valor de final es el nuevo ancho del menú
        self.animation.setEasingCurve(QtCore.QEasingCurve.InOutQuart)
        #self.animation.finished.connect(lambda: self.setAttribute(QtCore.Qt.WA_TranslucentBackground, True))  # Reactiva al finalizar
        self.animation.start()



    #Agregar eventos de presionado de mouse
    def mousePressEvent(self, event):
        #Conseguir la posición actual
        self.clickPosition = event.globalPos()
        #Se usa esto como valor para mover la ventana

    def restore_or_maximize_window(self):
        #Si la ventana está maximizada
        if self.isMaximized():
            self.showNormal()
            self.ui.restore_window_button.setIcon(QtGui.QIcon(u":/iconos/iconsselect/IconoirExpand.svg")) #Cambia ícono
        else:
            self.showMaximized()
            self.ui.restore_window_button.setIcon(QtGui.QIcon(u":/iconos/iconsselect/IconoirExpand.svg")) #Cambia ícono, actualmente es el mismo



#---------------------------------------------------EJECUTAR PROGRAMA-------------------------------------------------------

if __name__ == "__main__":
    #Calibration
    print("Iniciando calibración...")
    puntos = calibrate(camera_index=2, alpha_percent=20)
    cv2.destroyAllWindows() #COMO SEA ESTO ME MATO
    if len(puntos) < 3:
        a_coeffs = np.array([1, 0, 0], dtype=np.float32)
        b_coeffs = np.array([0, 1, 0], dtype=np.float32)
    else:
        a_coeffs, b_coeffs = train_mapping(puntos)
    print("Calibración lista. Coeficientes obtenidos.")

    #Launch UI
    app = QtWidgets.QApplication(sys.argv)
    window = MainWindow(a_coeffs, b_coeffs)
    window.show()

    sys.exit(app.exec_())

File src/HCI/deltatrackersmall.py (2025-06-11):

# OPEN SOURCED BY JASON ORLOSKY, CONTRIBUTION BY CHIN CANTILLO https://github.com/chindynamics


#Import dependencies

import cv2
import numpy as np
import random
import math
import pyautogui
import time

pyautogui.PAUSE = 0
pyautogui.FAILSAFE = False

camera_w = 640 #Modify to change camera width
camera_h = 480 #Modify to change camera height

#Smoothing filter state
_smoothed_center_persistent = None
lost_tracking_counter = 0

calibration_points = [] #Points of calibration

#Get screen resolution size
SCREEN_W, SCREEN_H = pyautogui.size()

def smooth_center(current_center, alpha_percent=80): #This function smooths the pupil center, for better cursor movement
    global _smoothed_center_persistent, lost_tracking_counter
    alpha = max(0.01, alpha_percent / 100.0)
    if current_center:
        lost_tracking_counter = 0
        if _smoothed_center_persistent:
            smoothed_x = int(alpha * current_center[0] + (1 - alpha) * _smoothed_center_persistent[0])
            smoothed_y = int(alpha * current_center[1] + (1 - alpha) * _smoothed_center_persistent[1])
            smoothed_center = (smoothed_x, smoothed_y)
        else:
            smoothed_center = current_center
        _smoothed_center_persistent = smoothed_center
    else:
        #lost tracking
        lost_tracking_counter += 1
        smoothed_center = _smoothed_center_persistent
    return smoothed_center

def train_mapping(calibration_points): #Mapping from camera to cursor
    #Matrixes for least squares
    P = [] 
    Sx = []
    Sy = []
    for (px, py), (sx, sy) in calibration_points:
        P.append([px, py, px*py, px*px, py*py, 1]) #Terminos cuadrados
        Sx.append(sx)
        Sy.append(sy)
    P = np.array(P, dtype=np.float32)
    Sx = np.array(Sx, dtype=np.float32)
    Sy = np.array(Sy, dtype=np.float32)
    #Solve for P * a = Sx, P * b = Sy
    a_coeffs, _, _, _ = np.linalg.lstsq(P, Sx, rcond=None)
    b_coeffs, _, _, _ = np.linalg.lstsq(P, Sy, rcond=None)
    return a_coeffs, b_coeffs


def calibrate(camera_index=1, alpha_percent=50):  #Calibration routine, 4x4 grid
    global calibration_points
    pasos = 6 #Dividir en pasos + 1 (puntos)
    grid = [(i / pasos, j / pasos) for j in range(pasos+1) for i in range(pasos+1)]

    #Windows prep
    cv2.namedWindow('Calibration', cv2.WINDOW_NORMAL)
    cv2.setWindowProperty('Calibration', cv2.WND_PROP_FULLSCREEN, cv2.WINDOW_FULLSCREEN)
    cv2.namedWindow('Calibration Camera', cv2.WINDOW_NORMAL)

    cap = cv2.VideoCapture(camera_index)
    cap.set(cv2.CAP_PROP_FRAME_WIDTH, camera_w)
    cap.set(cv2.CAP_PROP_FRAME_HEIGHT, camera_h)
    if not cap.isOpened():
        print("Error: No se pudo abrir la cámara para calibración.")
        return []

    for pct_x, pct_y in grid:
        #Draw points
        marker = np.zeros((SCREEN_H, SCREEN_W, 3), dtype=np.uint8)
        cx, cy = int(pct_x*SCREEN_W), int(pct_y*SCREEN_H)
        cv2.circle(marker, (cx, cy), 20, (255,255,255), -1)
        cv2.imshow('Calibration', marker)

        #Show camera while waiting for key
        while True:
            ret, frame = cap.read()
            if not ret:
                continue
            rotated_rect = process_frame(frame)
            current_center = None
            if rotated_rect and isinstance(rotated_rect, tuple):
                current_center = tuple(map(int, rotated_rect[0]))
                sm_center = smooth_center(current_center, alpha_percent)
                cv2.circle(frame, sm_center, 5, (0,0,255), -1)

            cv2.imshow('Calibration Camera', frame)
            key = cv2.waitKey(1) & 0xFF
            if key == ord(' '):  #Press space key for capture
                samples = []
                #Take 5 samples and get average
                for _ in range(5):
                    ret, f2 = cap.read()
                    if not ret:
                        continue
                    rr = process_frame(f2)
                    if rr and isinstance(rr, tuple):
                        cc = tuple(map(int, rr[0]))
                        sm = smooth_center(cc, alpha_percent)
                        samples.append(sm)
                    #Wait 
                    cv2.waitKey(50)

                if samples:
                    avg_x = int(sum(p[0] for p in samples) / len(samples))
                    avg_y = int(sum(p[1] for p in samples) / len(samples))
                    calibration_points.append(((avg_x, avg_y), (cx, cy)))
                break
            elif key == ord('q'):
                cap.release()
                cv2.destroyAllWindows()
                return calibration_points

    cap.release()
    cv2.destroyAllWindows()
    return calibration_points

#Crop the image to maintain a specific aspect ratio (width:height) before resizing.
def crop_to_aspect_ratio(image, width=640, height=480):
    current_height, current_width = image.shape[:2]
    desired_ratio = width / height
    current_ratio = current_width / current_height

    if current_ratio > desired_ratio:
        new_width = int(desired_ratio * current_height)
        offset = (current_width - new_width) // 2
        cropped_img = image[:, offset:offset+new_width]
    else:
        new_height = int(current_width / desired_ratio)
        offset = (current_height - new_height) // 2
        cropped_img = image[offset:offset+new_height, :]

    return cv2.resize(cropped_img, (width, height))

#Apply thresholding to an image
def apply_binary_threshold(image, darkestPixelValue, addedThreshold):
    threshold = darkestPixelValue + addedThreshold
    _, thresholded_image = cv2.threshold(image, threshold, 255, cv2.THRESH_BINARY_INV)
    return thresholded_image

# Finds a square area of dark pixels in the image
# @param image: BGR image
# @return a point within the pupil region
def get_darkest_area(image):
    ignoreBounds = 120 #It depends on resolution
    imageSkipSize = 20 #It depends on resolution
    searchArea = 10 #It depends on resolution
    internalSkipSize = 10

    gray = cv2.cvtColor(image, cv2.COLOR_BGR2GRAY)
    min_sum = float('inf')
    darkest_point = None

    for y in range(ignoreBounds, gray.shape[0] - ignoreBounds, imageSkipSize):
        for x in range(ignoreBounds, gray.shape[1] - ignoreBounds, imageSkipSize):
            current_sum = 0
            num_pixels = 0
            for dy in range(0, searchArea, internalSkipSize):
                if y + dy >= gray.shape[0]:
                    break
                for dx in range(0, searchArea, internalSkipSize):
                    if x + dx >= gray.shape[1]:
                        break
                    current_sum += gray[y + dy][x + dx]
                    num_pixels += 1

            if current_sum < min_sum and num_pixels > 0:
                min_sum = current_sum
                darkest_point = (x + searchArea // 2, y + searchArea // 2)

    return darkest_point
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
